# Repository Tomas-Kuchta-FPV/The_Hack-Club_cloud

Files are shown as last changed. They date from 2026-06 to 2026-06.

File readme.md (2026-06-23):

# The Hack Club cloud
Hack club alows teenagers to build their dream projects.  
So why not to visualize it and show it off at Open Sauce! It's all about bringing crazy ideas to real life.  
We are going to build a huge LED cloud wall matrix at the outpost hackathon with like a lot of people, and it's going to be awesome!  
This is so ambitious and crazy - LEDs build it!  
You can also folow the jurney here https://stardance.hackclub.com/projects/21092.  

Have you ever heard of cloud walls? Most of them are a static color, but this one's going to be almost like a LED matrix but clouds!  

 My vision for this peoject is defined in vision board.png. Build instructions are in build_plan.md, Schematic+block_diagram.drawio.pdf and LEDstand.pdf.

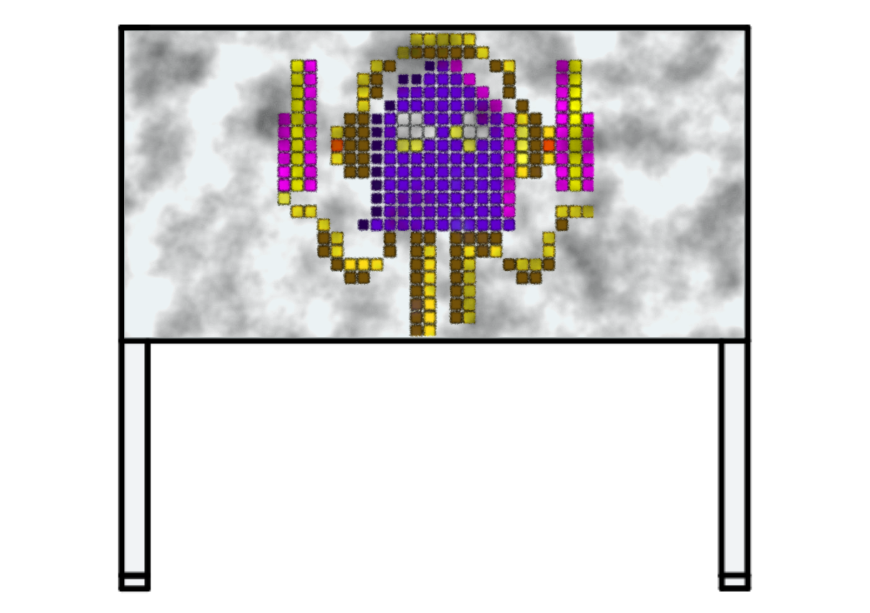
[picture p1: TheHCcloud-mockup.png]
Mockup
  
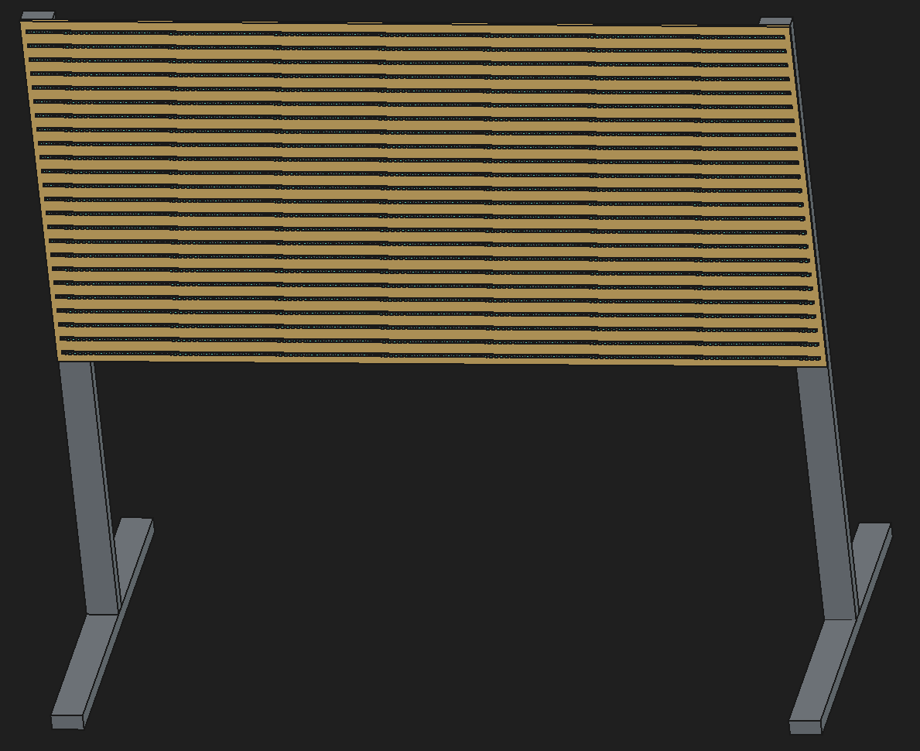
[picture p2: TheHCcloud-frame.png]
frame
  

## Design Constraints
- Price should be a concern
- The LED strips have 10cm segments and toy can addres the whole segment at once.
- 60LEDs/m, 18W/m, power injextion evhery 20m

*Here are the results of my calculations*
Word definition:  
There are going to be 24segments in a row which eqates to 2,4m.  
The LED colums are going to be in pairs of two. There are going to be 24 individualy adressable rows with 48 rows in total.  
x = 24 segments => 240cm  
y = 12 adresable rows => 24 rows in total of *x*  

### Sumary
| Item | Value |
| --- | --- |
| Total strip length | 57.6 m |
| 15 m reels needed | 4 reels |
| Spare strip | 2,4 m |
| total LEDs adressable (segments) | 288 LEDs |
| LEDs total | 1728 LEDs  |
| Logical matrix (24 paired columns) | 24 × 12 |
| Maximum power | ≈ 1036,8 W |
| Maximum current @ 24 V | ≈ 43,2 A |

## SW
This project is going to use well known FW called WLED with a my DIY lightning controller called [TwinkleTron](https://github.com/Tomas-Kuchta-FPV/TwinkleTron-Wled-Controller).  
I'm also open for experimentation from the comunity. We can also code something like a snake game or tetris.  

## Pivot tracking
1. Make a matrix out of smart wifi LED bulbs. - it's going to be super expensive like $3k 
2. Use Adressable LED string light. Either the Christmas style light chain or wall mountable ones
3. *Use cheap adressable LED strips with [TwinkleTron](https://github.com/Tomas-Kuchta-FPV?tab=repositories&q=twinkle) to make a matrix covered in cloud stuff**
4. One step further - An adressable cloud wall!!!!

## Game plan
- [x] get CADing and CAD out the matrix
  - [x] Make build plans
  - [x] Make a beutifull readme.md
  - [x] Post it!
- [ ] build out and test the WLED code at home with the help of [TwinkleTron](https://github.com/Tomas-Kuchta-FPV/TwinkleTron-Wled-Controller)
  - [x] Configure it
  - [ ] Make cool light effects sequence
  - [ ] and if there is time, interface with it and make some fun game like a snake

- [ ] Get all the needed parts to the outpost hackathon venue - IDK how please help
- [ ] Build it there!!!! - We are going to loosely follow instructions.md
- [ ] Exhibit it! :)
- [ ] And maybe we can give it to someone or action it off. (I hope that will spark some teens interest :)

## BOM
| Item | Qty | Price ($) | Link/Source | Note |
| --- | --- | --- | --- | --- |
| LED Strips | 15m * 4 | 49.48 * 4 | [Amazon](https://www.amazon.com/BTF-LIGHTING-Addressable-100Pixels-Non-Waterproof-Respberry/dp/B0DCG5G9VQ) | The main part lol |
| 1000uF 25V Caps | ~10 | 7 | [Amazon](https://www.amazon.com/10x20mm-Electrolytic-Capacitor-Aluminum-Capacitors/dp/B0F8C1VMT6/ref=sr_1_6) | It will filter out the voltage spikes |
| Pillow fill | 5 lbs | 25 | [Amazon 1](https://www.amazon.com/Fairfield-Poly-Premium-Fiber-32-Ounce/dp/B002OUP6JE/) or [Amazon 2](https://www.amazon.com/Jecqbor-Polyfill-Stuffing-Polyester-Fiberfill/dp/B0G2WZL4Z2/) | the cloud material |
| Light blue spray paint | 1 | 7 | [Home Depot](https://www.homedepot.com/p/Rust-Oleum-Painter-s-Touch-2X-12-oz-Satin-Seaside-General-Purpose-Spray-Paint-334095/307244941) | To make the OBS pretier |
| Spray adhesive | 2 | 13 * 2 | [Home Depot](https://www.homedepot.com/p/Gorilla-14-oz-Spray-Adhesive-6301502/303508262) | to attach the cloud to the OBS |
| 3 strand wire 20awg | 32ft | 16.13 | [Amazon](https://www.amazon.com/BTF-LIGHTING-Electrical-Extension-Connection-Changing/dp/B0C81L9GT7/ref=sr_1_2) | Better for signal and low pewer |
| 2 strand wire 10awg | 30ft / 10m | 61 | [Home Depot](https://www.homedepot.com/p/Vrbgify-30-ft-12-Gauge-2-Conductors-Stranded-Grounded-Landscape-Lighting-Wire-Cut-Flexible-Copper-Clad-Aluminum-PVC-BSA1127D443/341232845) | LED power injection |
| 24V PSU - 1200W | 1 | 70 | [Amazon](https://www.amazon.com/VAYALT-Switching-Universal-Transformer-Industrial/dp/B0FCSK1M9K/) | to power the crazy contraption |
| USA power plug | 1 | 5 | [Amazon](https://www.amazon.com/Computer-Monitor-Printer-PlayStation-Asus-ETL/dp/B0FNML9SRY) | for connecting to the grid |
| WAGOS! | 10 | 9 | [Home Depot](https://www.homedepot.com/p/WAGO-221-413K006-000-3-Wire-Lever-Nuts-Conductor-Compact-Splicing-Connectors-12-24-AWG-10-Pack-221-413K006-000/334555570) | I'm almost german lol |
| TwinkleTron | 1 | - | I'll grab it from home | DIY lightning controller :) |

*Subtotal:* HD $93,71 | A $322.01

**Stand**
| Item | Qty | Price ($) | Link/Source | Note |
| --- | ----- | --- | --- | --- |
| OBS Board | 2 | 11 | [Home Depot](https://www.homedepot.com/p/OSB-7-16-Application-as-4ft-X-8-ft-Sheathing-Panel-386081/202106230) | Everything will attach to it |
| 2x4 lumber | 3 | 17,4 | [Home Depot](https://www.homedepot.com/p/2-in-x-4-in-x-8-ft-2-Premium-Grade-Dimensional-Lumber-441317/202094172) | Posts to raise it up. |
| Screws | 1 box | 12 | [Home Depot](https://www.homedepot.com/p/Grip-Rite-9-x-3-in-Star-Drive-Dual-Flat-Head-Coarse-Thread-Construction-Screws-1-lb-Box-3GCS1/204959258) | Kinda self explanatory |
| Home depod delivery  ¯\_(ツ)_/¯ | - | 79 | | The logistics should be discussed with alexren |

*Subtotal:* HD $119.4 | A $0

**Tools**
| Item | Qty | Price ($) | Link/Source | Note |
| --- | --- | --- | --- | --- |
| Impact driver | - | - | Can be borrowed |
| Saw | - | - | Can be borrowed |
| Soldering iron | - | - | Can be borrowed |
| Hot glue gun | - | - | Can be borrowed |
| pernament marker | 3 | - | |
| Crazy ampermeter to mesure 80A IG | 2 | - | ? |
| Multimeter | - | - |
| power cord | 2 | 27*2 | [Amazon](https://www.amazon.com/Skrizcable-Extension-Waterproof-Weatherproof-Retardant/dp/B0G7XSZJPC) |
| Electrical tape | 6 pack | 10 | [Home Depot](https://www.homedepot.com/p/Commercial-Electric-1-2-in-x-20-ft-Electric-Tape-Multi-Color-6-Pack-30005336/206874157) | You never know when you need it |

*Subtotal:* free 99 if we borrow

**Total (excluding tools):** $535,12

## Other
Here is the parent repo:  
https://github.com/Tomas-Kuchta-FPV/MatrixShow

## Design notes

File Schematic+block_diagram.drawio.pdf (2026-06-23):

Exhibition
outlets

String 1 -

24V PSU
1200W

+

String 2 -

String 1 +

String 2 +

String 3 -

String 4 -

String 3 +

String 4 +

String 1 -`

String 1 +
WAGO
3wire

WAGO
3wire

Start PI
1/4 PI

PI = Power Injection

Start PI
1/4 PI

String 2 -`

String 2 +
WAGO
3wire

WAGO
3wire

2/4 PI
2/4 PI

2/4 PI
2/4 PI

String 3 -`

String 3 +
WAGO
3wire

WAGO
3wire

3/4 PI
3/4 PI

3/4 PI
3/4 PI

String 4 -`

String 4 +
WAGO
3wire

WAGO
3wire

4/4 PI
END PI

4/4 PI
END PI

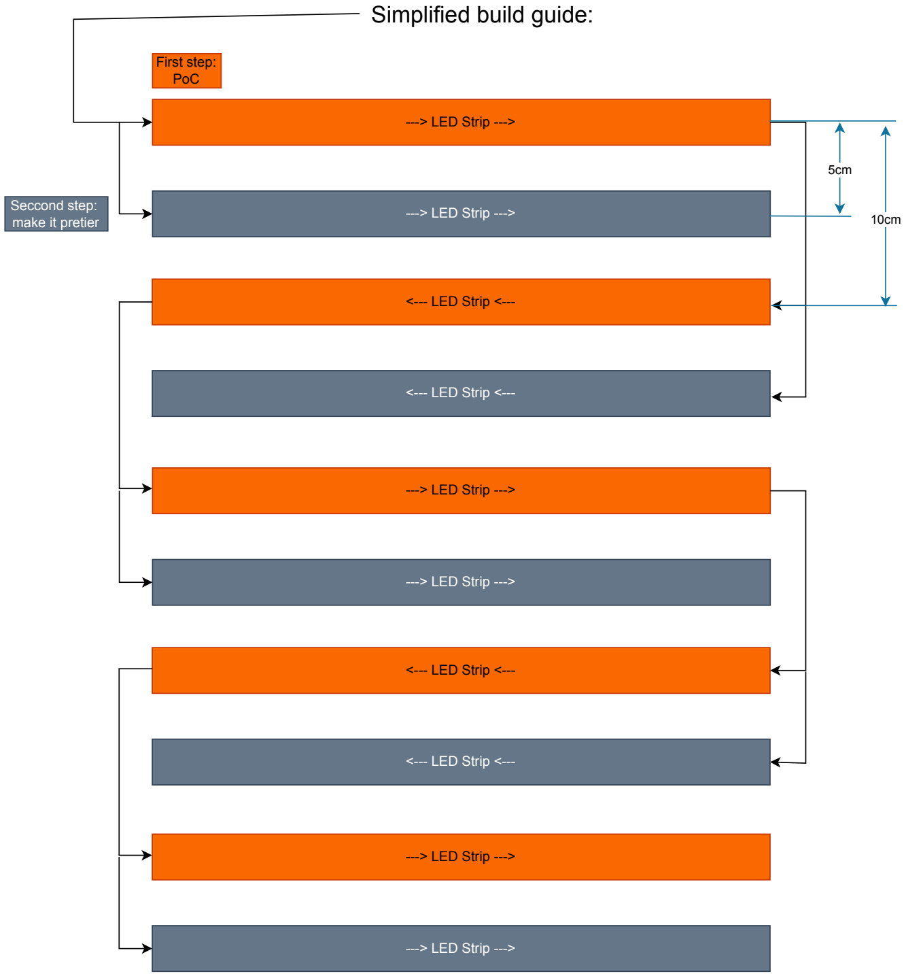
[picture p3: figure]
Simplified build guide:; ---> LED Strip --->; First step: PoC; <--- LED Strip <---; Seccond step:; make it pretier

LED cloud matrix

Start PI

2/4 PI

3/4 PI

3/4 PI | END PI

1/4 PI

2/4 PI

3/4 PI

4/4 PI

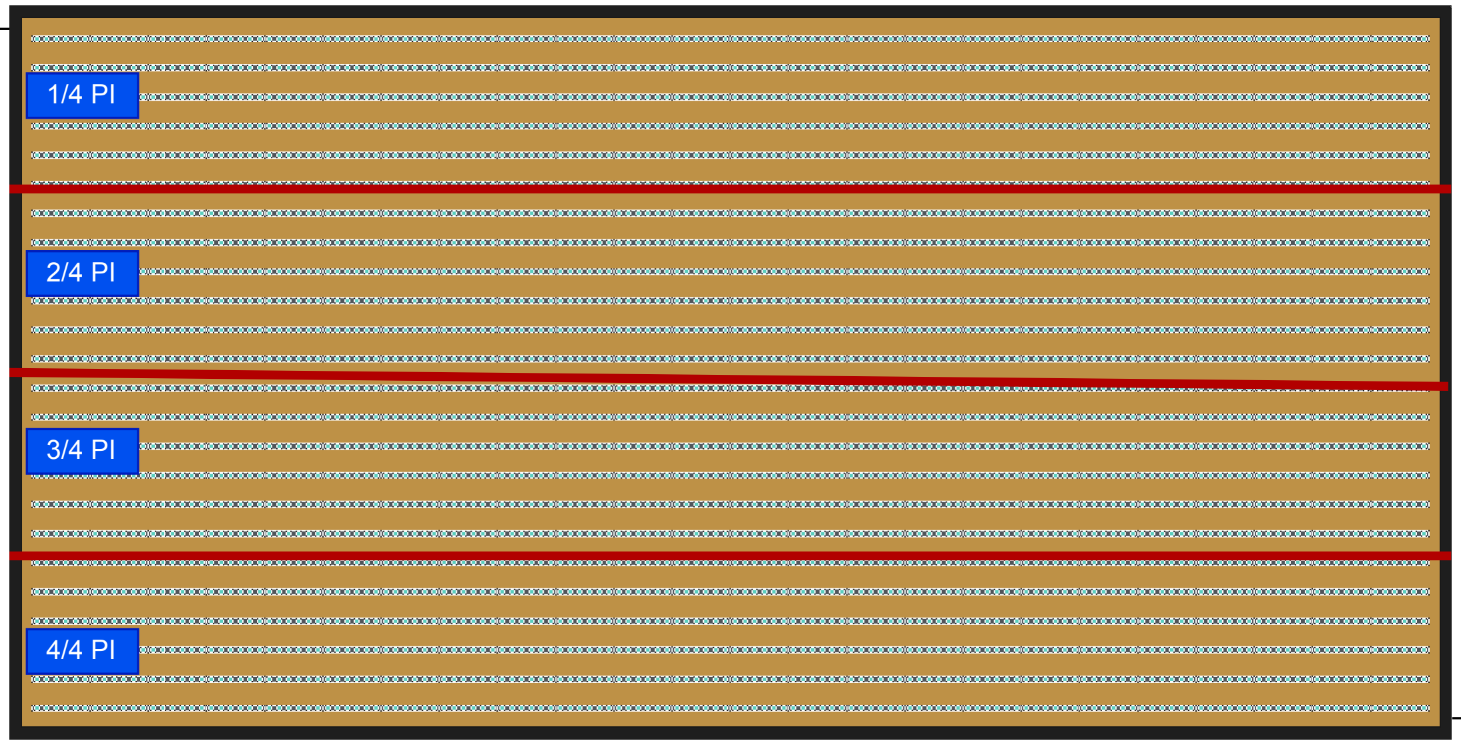
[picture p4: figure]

Start PI

END PI

Power Injection

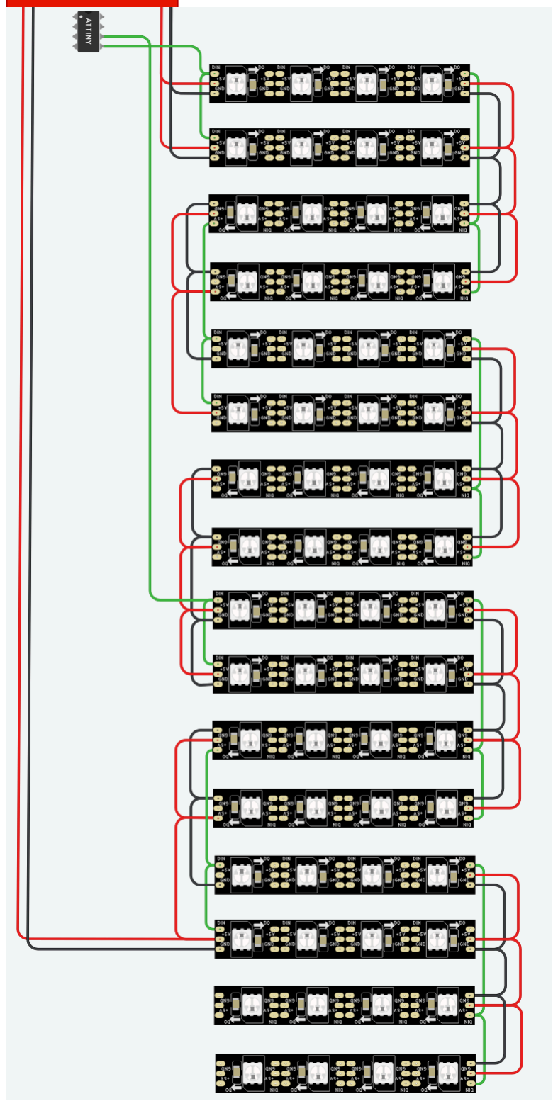
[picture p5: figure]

https://www.tinkercad.com/things/bL3QT8HwlBd/editel?sharecode=sLQEeuwQUxZXSeigR7AWRiwaa5n5Avw2JMpWevVZltQ

Text definotion: (Yapping is normal in electrotechnics)
The LED stripps will be all wired in paralled with even power injection. For now I see the need for 8 Power injections along the way, but we'll find out later when we wire all the LED strips in series and then we can worry about power injections.
The LED sptrip wiring is interesting, as there will be two strips wired in paralell and they will share the same pixel mapping because of they're wired in paralel. Then it will go to the two strips below and etc.

And in the middle we have to have another GPIO from TwinkleTron for the bottom rows as I don't think the signal would be suitable as this point.

Almost evhery wire is going on the backside, with local connections being on the front side, That's also true for BCB's lol.

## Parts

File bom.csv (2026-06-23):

Item | Qty | Price ($) | Link/Source
LED Strips | 15m * 4 | 49.48 * 4 | [Amazon](https://www.amazon.com/BTF-LIGHTING-Addressable-100Pixels-Non-Waterproof-Respberry/dp/B0DCG5G9VQ)
1000uF 25V Caps | ~10 | 7 | [Amazon](https://www.amazon.com/10x20mm-Electrolytic-Capacitor-Aluminum-Capacitors/dp/B0F8C1VMT6/ref=sr_1_6)
Pillow fill | 5 lbs | 25 | [Amazon 1](https://www.amazon.com/Fairfield-Poly-Premium-Fiber-32-Ounce/dp/B002OUP6JE/) or [Amazon 2](https://www.amazon.com/Jecqbor-Polyfill-Stuffing-Polyester-Fiberfill/dp/B0G2WZL4Z2/)
Light blue spray paint | 1 | 7 | [Home Depot](https://www.homedepot.com/p/Rust-Oleum-Painter-s-Touch-2X-12-oz-Satin-Seaside-General-Purpose-Spray-Paint-334095/307244941)
Spray adhesive | 2 | 13 * 2 | [Home Depot](https://www.homedepot.com/p/Gorilla-14-oz-Spray-Adhesive-6301502/303508262)
3 strand wire 20awg | 32ft | 16.13 | [Amazon](https://www.amazon.com/BTF-LIGHTING-Electrical-Extension-Connection-Changing/dp/B0C81L9GT7
2 strand wire 10awg | 30ft / 10m | 61 | [Home Depot](https://www.homedepot.com/p/Vrbgify-30-ft-12-Gauge-2-Conductors-Stranded-Grounded-Landscape-Lighting-Wire-Cut-Flexible-Copper-Clad-Aluminum-PVC-BSA1127D443/34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
24V PSU - 1200W | 1 | 70 | [Amazon](https://www.amazon.com/VAYALT-Switching-Universal-Transformer-Industrial/dp/B0FCSK1M9K/)
USA power plug | 1 | 5 | [Amazon](https://www.amazon.com/Computer-Monitor-Printer-PlayStation-Asus-ETL/dp/B0FNML9SRY)
WAGOS! | 10 | 9 | [Home Depot](https://www.homedepot.com/p/WAGO-221-413K006-000-3-Wire-Lever-Nuts-Conductor-Compact-Splicing-Connectors-12-24-AWG-10-Pack-221-413K006-000/334555570)
TwinkleTron | 1 | - | I'll grab it from home
OBS Board | 2 | 11 | [Home Depot](https://www.homedepot.com/p/OSB-7-16-Application-as-4ft-X-8-ft-Sheathing-Panel-386081/202106230)
2x4 lumber | 3 | 17,4 | [Home Depot](https://www.homedepot.com/p/2-in-x-4-in-x-8-ft-2-Premium-Grade-Dimensional-Lumber-441317/202094172)
Screws | 1 box | 12 | [Home Depot](https://www.homedepot.com/p/Grip-Rite-9-x-3-in-Star-Drive-Dual-Flat-Head-Coarse-Thread-Construction-Screws-1-lb-Box-3GCS1/204959258)
Home depod delivery ¯\_(ツ)_/¯ | - | 79

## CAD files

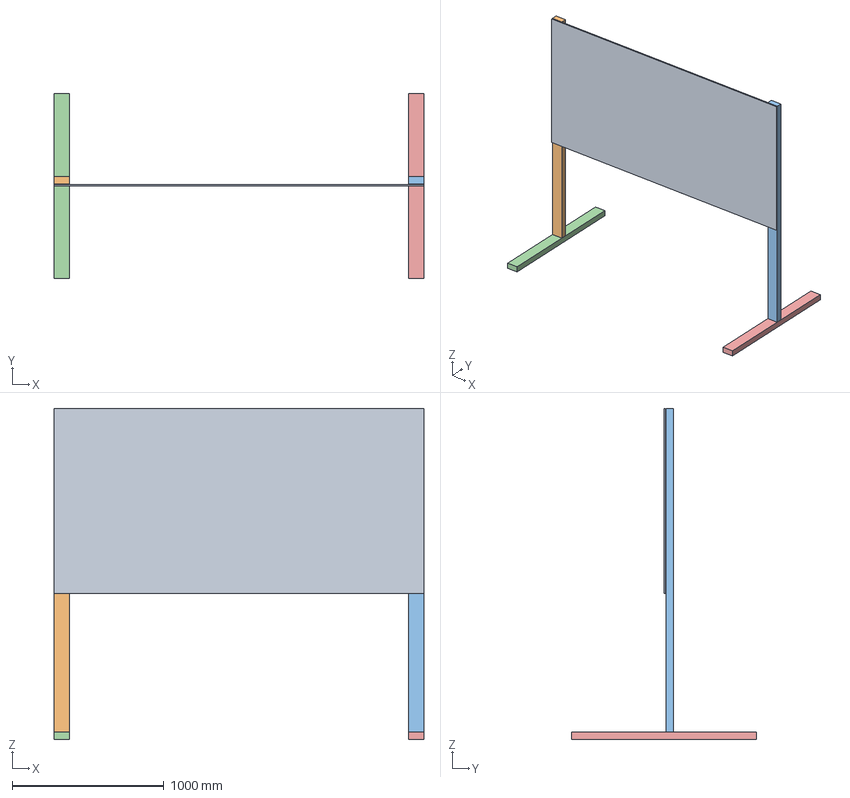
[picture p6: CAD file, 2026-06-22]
OpenSauceExhibit.FCStd
2438.8 x 1219.2 x 2185.0 mm
OBS001
2x4 1
2x4 2
2x4 bot 1
2x4 bot 2

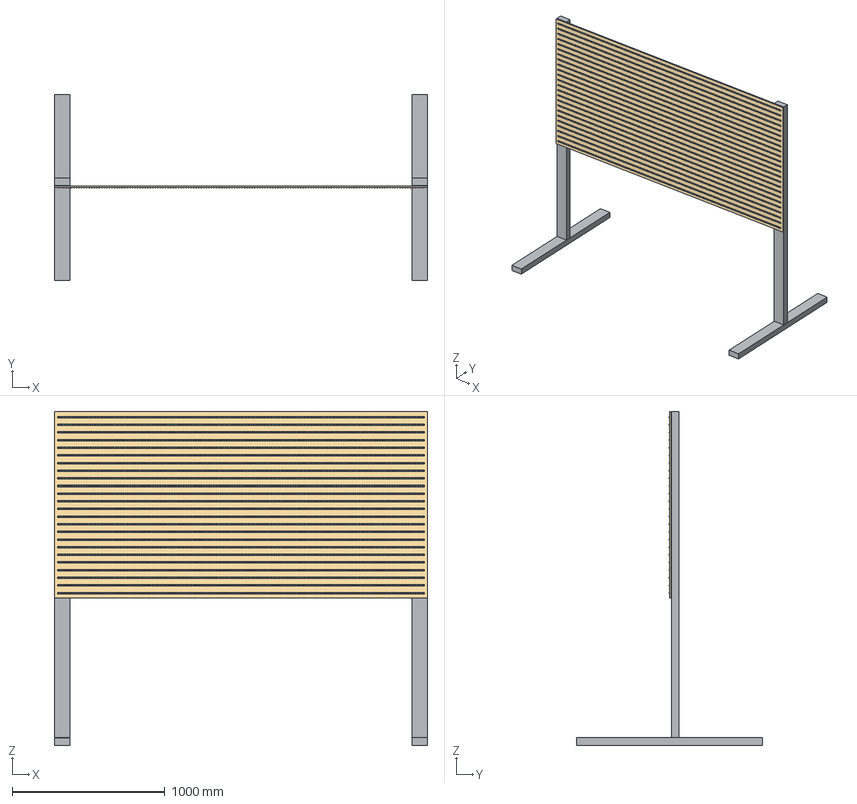
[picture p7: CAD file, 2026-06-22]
TheHCcloud.step
2438.8 x 1219.2 x 2185.0 mm
OBS001
LED strip segment x 576
2x4 1
2x4 2
2x4 bot 1
2x4 bot 2

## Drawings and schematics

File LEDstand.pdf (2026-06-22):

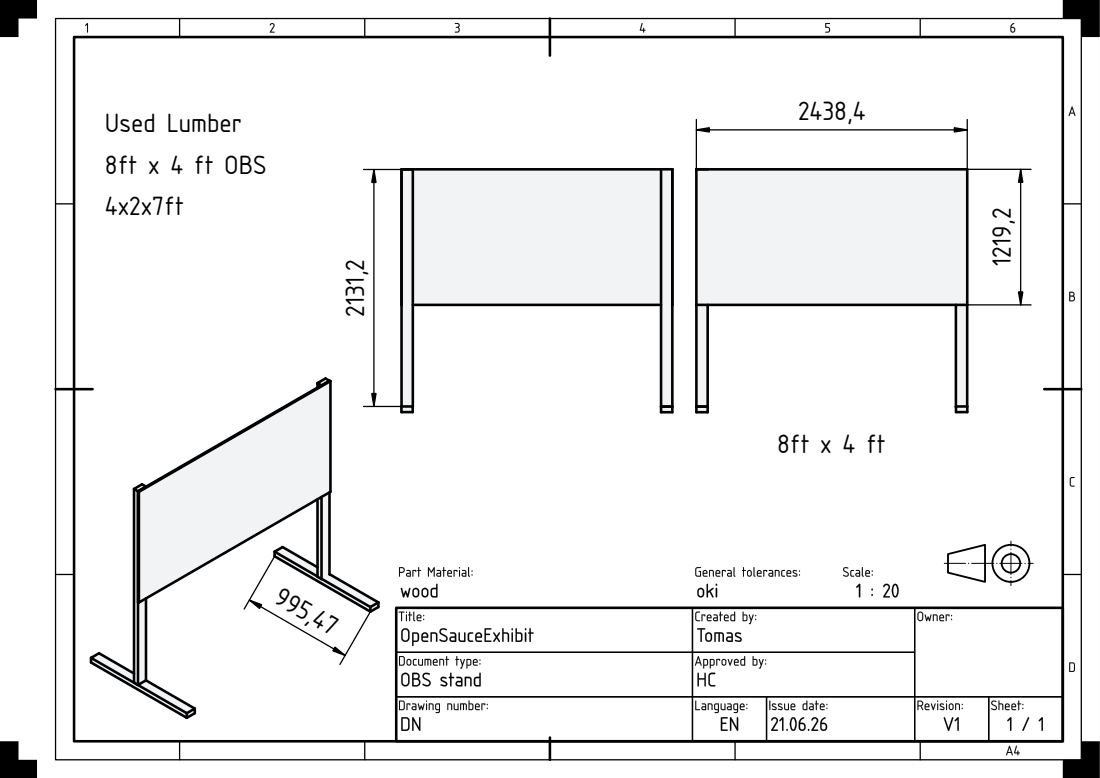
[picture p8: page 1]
Used Lumber 8ft x 4 ft OBS

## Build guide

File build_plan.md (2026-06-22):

# How do we build it? What's the plan?
1. I'll design it with the input from hack clubbers
2. Then we'll submit to outpost!
3. Get the parts shipped to the venue (The logistics are still a bit unclear need to discuss with alexren)
4. Build it together! I think we could make it with ~5 people
5. And show it off at Open Sauce!
6. Get rid of it somehow. Probably auction it or give it to someone at open sauce.

## Build.exe
1. we'll begin with the OBS board.
2. we cut the LEd strips to length
3. while other people starts gluing the strips on with the availible plans - we'll begin with just the normal config wo the extra strip running in paralel
4. and after a few rows some people will start soldering the strips in series - without worrying about power injection
5. after a few rows we will test it, and hopefully it works on the first try
6. and when the MVP is finished we are going to try get it up an working
7. while we were working on the matrix somebody will wire up the PSU
8. Then we begin injecting powah! as defined by the schematic
9. Insure that it works, kinda like a bench test but it's a RGB desk lol
10. let's finish it up! attach the PSU to the OBS, the 2x4 legs and we're basically done
11. start gluing on the pillow fill clouds
12. And now we can tweak the WLED controller, I really hope that sombody can hack on snake :)

We are so finished rn  
Thanks y'all

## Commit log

2026-06-20 got the fist draft done of pivot #4
    [OpenSauceExhibit.FCStd]
2026-06-21 created schematic and refined BOM
    [OpenSauceExhibit.FCStd]
2026-06-22 added a build plan and finished the CAD.
    [OpenSauceExhibit.FCStd]
2026-06-22 Finishing touches
    [OpenSauceExhibit.FCStd, TheHCcloud.step]
2026-06-23 Updated the BOM and calculations as they weren't correct.
    [bom.csv]
